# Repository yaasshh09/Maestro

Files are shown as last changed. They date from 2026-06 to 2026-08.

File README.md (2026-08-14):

# Maestro
 
A compact 6-key macropad with a rotary encoder and OLED display, built around the Seeeduino XIAO RP2040 and running QMK firmware. Small footprint, fully custom, and 3D printed.

## Overview
 
This is a 6-key macropad arranged in a 2x3 matrix, with a rotary encoder for analog-style control and a 0.91" OLED for live feedback. It is built on a custom PCB, with the Seeeduino XIAO RP2040 socketed on top. It runs QMK, so every key, layer, and encoder action is fully remappable, and you get access to the entire QMK feature set (layers, tap-dance, macros, combos.
 
The whole thing is housed in a 3D printed case designed to hold the PCB, switches, encoder, OLED, and XIAO board in place.

<p align="center">
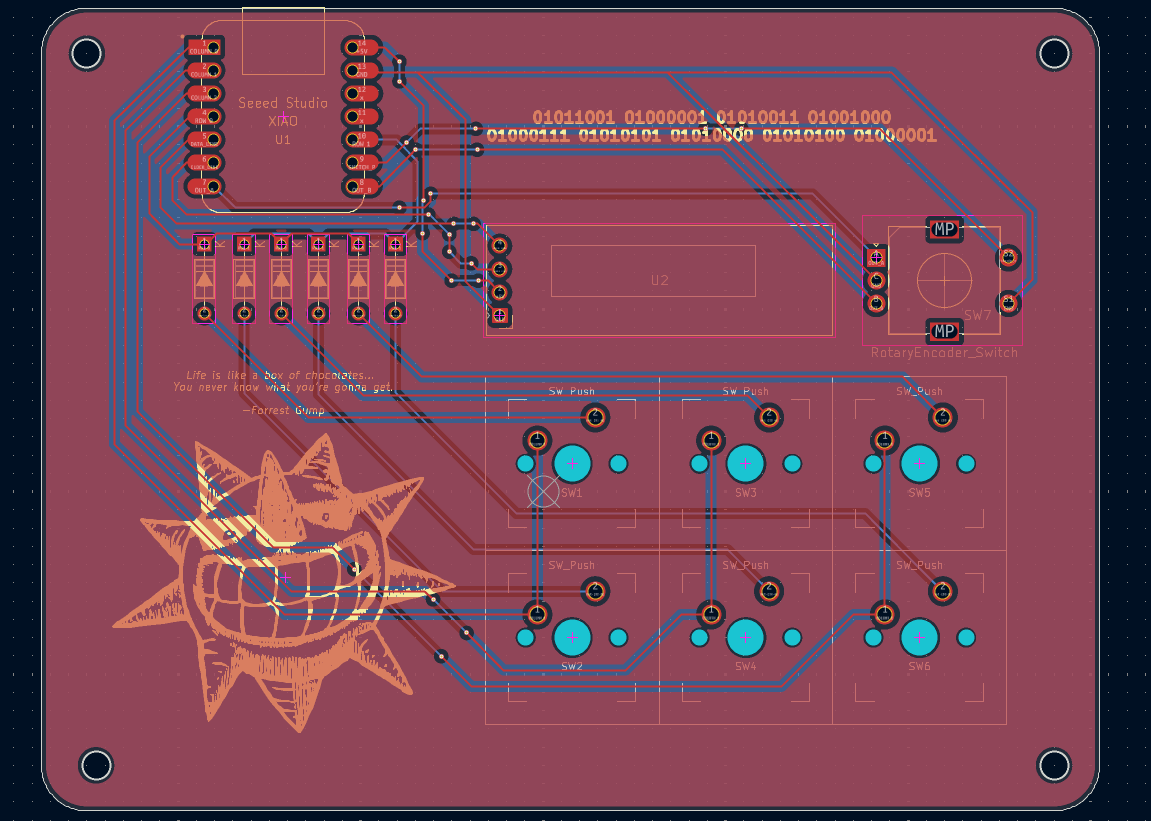
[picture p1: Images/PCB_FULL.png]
PCB_FULL
   
</p>
<p align="center">
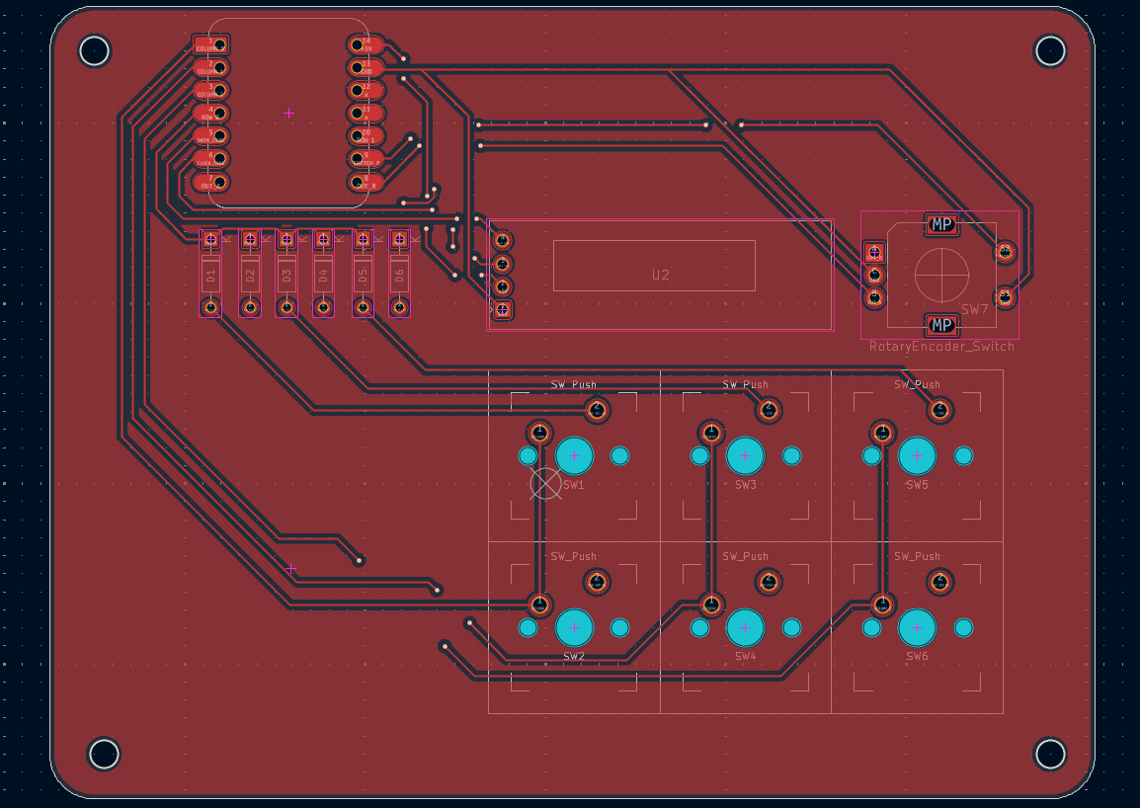
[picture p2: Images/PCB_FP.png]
  
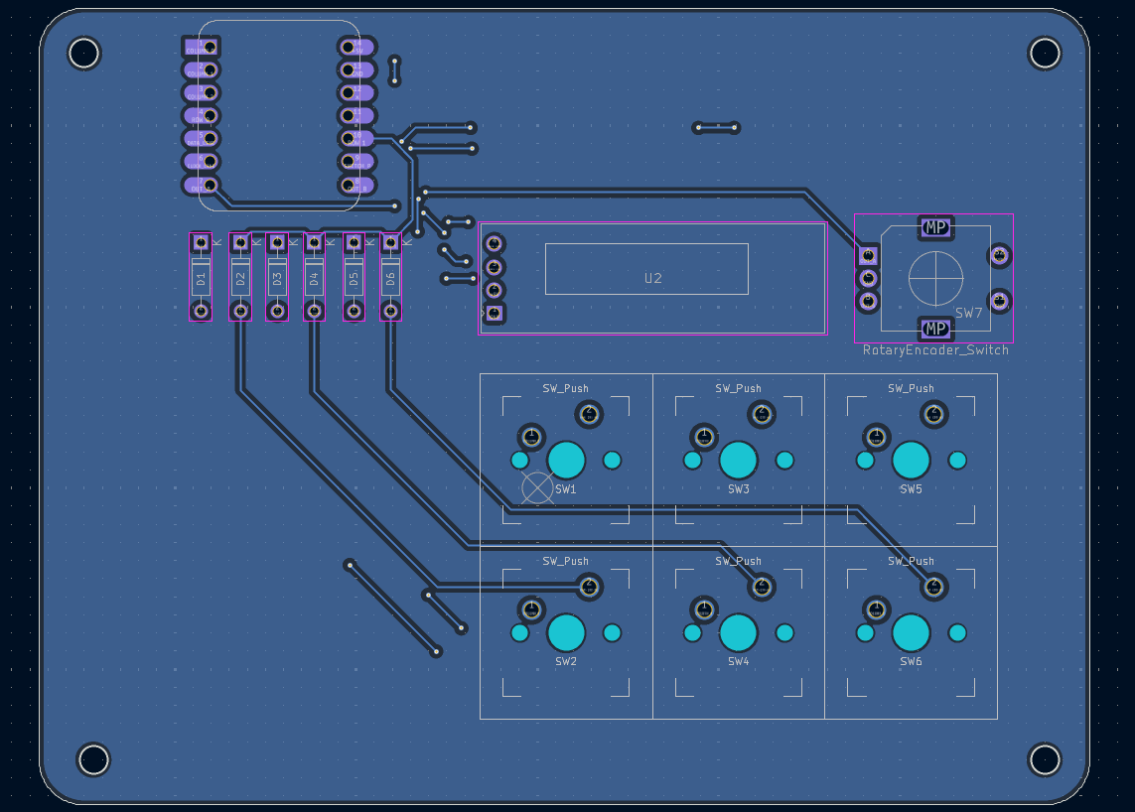
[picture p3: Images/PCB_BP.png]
 
</p>
<p align="center">
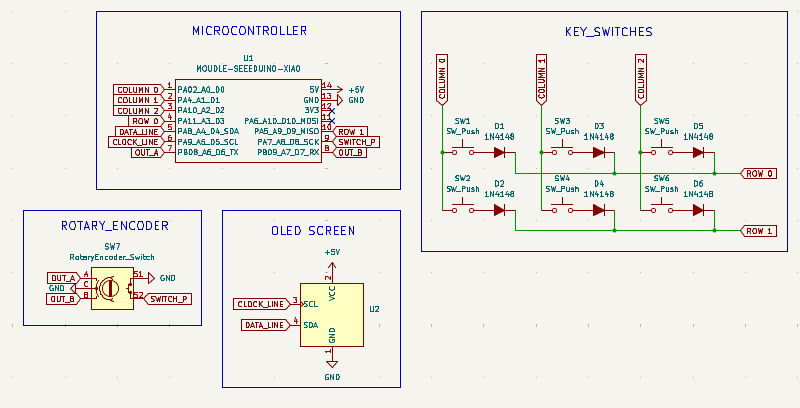
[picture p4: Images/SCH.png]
   
</p>
## Features
 
- 6 mechanical switches wired in a 2x3 matrix
- Rotary encoder with push-button
- 0.91" OLED display for layer and status readout
- Seeeduino XIAO RP2040 microcontroller
- Runs QMK firmware with full layer and macro support
- Custom designed PCB with socketed XIAO RP2040
- 3D printed three-part case

## Bill of Materials
|Amount|Part|
|-|-|
|1x|Seeeduino XIAO RP2040|
|6x|MX-style switches|
|6x|1N4148 diodes|
|1x|EC11 rotary encoder + knob|
|1x|0.91" SSD1306 OLED (I2C, 4-pin)|
|1x|custom PCB|
|1x|3D printed case (top + plate + base)|
|1x|USB-C cable|
 
## FIRMWARE (QMK)
### 1. Set up QMK

If you haven't already, install QMK and its toolchain:

```bash
qmk setup
```

On Windows, run all *qmk* commands inside the *QMK MSYS* terminal that is
installed with QMK.

### 2. Link this keyboard into your QMK tree

Clone this repo, then link `qmk_firmware/keyboards/maestro` to the keyboard
folder here. 

**Useful scripts:**

**Windows**:

```powershell
cd Firmware\Link
.\link-keyboard.ps1                                  
```
*or :*
```powershell
.\link-keyboard.ps1 -QmkHome "D:\path\to\qmk_firmware"
```

### 3. Build
```bash
qmk compile -kb maestro -km default
```

The compiled maestro_default.uf2 is written to the root of your qmk_firmware folder.

### 4. Flash

Put the XIAO RP2040 into bootloader mode. Either drag the `.uf2` onto that drive, or run:

```bash
qmk flash -kb maestro -km default
```

## OLED Display
 
The 0.91" OLED can show whatever you program in `oled_task_user()`. Common uses:
 
- Current active layer
- Caps/lock status
- A logo or small animation
- Encoder mode indicator

*Keep in mind the 128x32 resolution is small, so stick to short text or compact bitmaps.*

## OLED Companion App

OLED Display cant fetch data itself (keyboard has no internet). A Small external companion app runs on the host computer, reads current Spotify track, pushes to pad over raw HID through app.

- Spotify playing: OLED shows song and artist.
- Spotify idle: OLED shows current time and date.

Firmware just displays what the app sends.

**Requires RAW_ENABLE = yes in rules.mk.**
 
---   
 
## CAD

3D printed, three stacked layers:

- Base layer: tray with raised perimeter wall, four corner screw posts, USB-C notch on side. Houses PCB, secured with screws through corner posts.

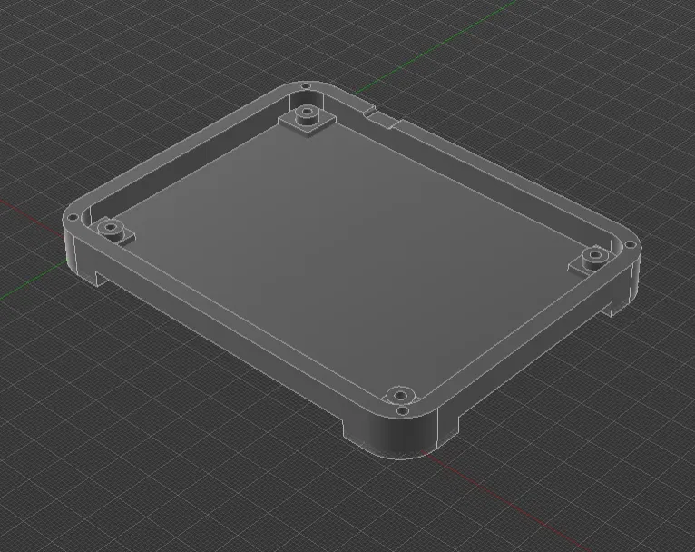
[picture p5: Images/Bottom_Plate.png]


- Plate layer: flat sheet with six square switch cutouts in 2x3 grid and raised border wall. Fixed with single screw at bottom, plus optional superglue for extra hold.

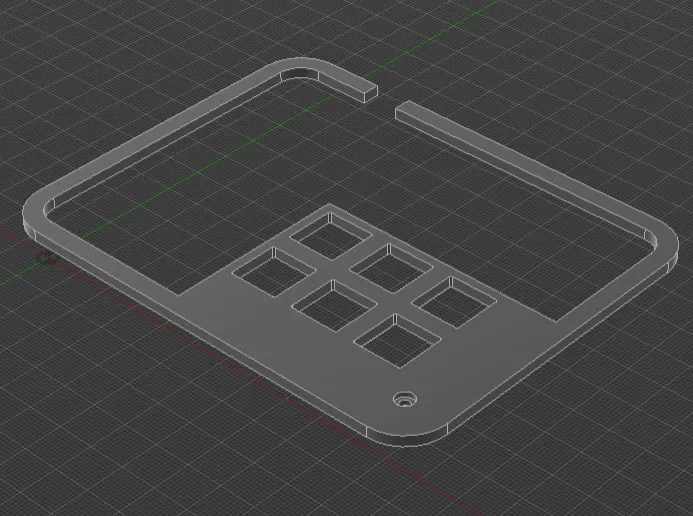
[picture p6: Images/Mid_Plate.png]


- Top layer: frame with large open window to showcase PCB, dedicated cutout slot for OLED and rotary encoder, screw hole, chamfered corners.

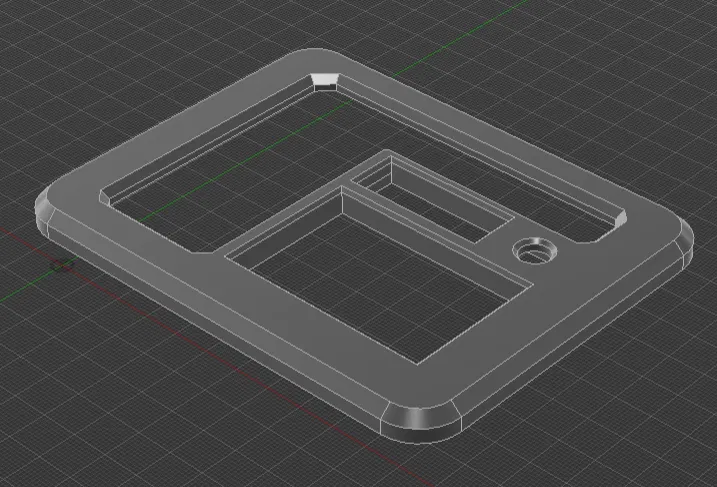
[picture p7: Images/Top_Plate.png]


---

## Notes
 
- Match your matrix and encoder pins in keyboard.json / config.h to the PCB routing before flashing.
- If the OLED does not light up, confirm the I2C address (usually 0x3C) and the header orientation.
- If the keys ghost or repeat, check diode placement and matrix definitions.

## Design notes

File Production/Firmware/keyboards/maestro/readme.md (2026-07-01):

# maestro

A 6-key (2x3) macropad with a rotary encoder and a 0.91" SSD1306 OLED, driven by
a Seeed **XIAO RP2040**.

* Keyboard Maintainer: [Yash](https://github.com/yaasshh09)
* Hardware Supported: Seeed XIAO RP2040 + 6x SW_Push (1N4148 per key), EC11 rotary
  encoder, 0.91" 128x32 SSD1306 OLED (I2C)

> Note: the PCB uses the generic Seeed XIAO footprint and the schematic
> specifies the **XIAO RP2040**, which this firmware targets. If you socket a
> different XIAO variant, update `processor`, `bootloader`, and the pins in
> `keyboard.json` / `config.h`.

## Wiring (schematic net -> XIAO pad -> RP2040 GPIO)

| Net | XIAO pad | GPIO  | Role |
|---|---|---|---|
| COLUMN 0/1/2 | D0/D1/D2 | GP26/GP27/GP28 | Matrix columns |
| ROW 0 | D3 | GP29  | Matrix row 0 |
| ROW 1 | D9 | GP4 | Matrix row 1 |
| DATA_LINE (SDA)| D4 | GP6 | OLED I2C1 SDA |
| CLOCK_LINE(SCL)| D5 | GP7 | OLED I2C1 SCL |
| OUT_A | D6 | GP0 | Encoder A |
| OUT_B | D7 | GP1 | Encoder B |
| SWITCH_P | D8 | GP2 | Encoder push (direct read) |

Diodes are COL2ROW (anode on the column, cathode on the row).

## Default layout

```
┌─────┬─────┬─────┐
│ Undo│ Copy│Paste│
├─────┼─────┼─────┤
│ Cut │ Redo│ Save│
└─────┴─────┴─────┘
  Encoder: turn = volume, press = mute
```

(Ctrl-based shortcuts; remap freely in `keymaps/default/keymap.c`.)

## OLED (now-playing / clock)

The OLED renders 4 rows of text streamed from a PC companion app over Raw HID:
the current Spotify song while playing, otherwise the time & date. Setup lives in
[`Firmware/companion/`](../../companion/README.md). With the app not running, the OLED shows a
static `maestro` fallback. All layout/formatting is in the companion script — no
reflashing needed to change it.

Make example for this keyboard (after setting up your build environment):

    make maestro:default

Flashing example for this keyboard:

    make maestro:default:flash

See the [build environment setup](https://docs.qmk.fm/#/getting_started_build_tools) and the [make instructions](https://docs.qmk.fm/#/getting_started_make_guide) for more information. Brand new to QMK? Start with our [Complete Newbs Guide](https://docs.qmk.fm/#/newbs).

## Bootloader

Enter the bootloader in 2 ways:

* **Double-tap reset**: quickly double-tap the XIAO RP2040 reset button; it mounts
  as a `RPI-RP2` USB drive — drop the `.uf2` on it.
* **Bootmagic reset**: hold the top-left key (matrix `[0,0]`) while plugging in.

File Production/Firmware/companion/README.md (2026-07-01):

# maestro OLED companion

A small background program that streams **now-playing** (Spotify / any Windows
media session) and the **clock** to the maestro macropad's OLED over Raw HID.

The firmware just renders 4 rows of text that this app sends, so you can change
the layout/format by editing `maestro_oled.py` alone — no reflashing.

```
Spotify playing                Nothing playing
┌─────────────────────┐        ┌─────────────────────┐
│ Bohemian Rhapsody    │        │ 14:35:07            │
│ Queen                │        │ Tue 01 Jul 2026     │
│                      │        │                     │
│ Spotify              │        │ maestro             │
└─────────────────────┘        └─────────────────────┘
```
(Long titles/artists scroll automatically.)

See [INSTALL.md](INSTALL.md) for the step-by-step end-user guide.

## Requirements

Use the **python.org** Python (3.9+), *not* the MSYS one bundled with QMK.

```powershell
pip install -r requirements.txt
```

This installs `hidapi` (USB) and `winsdk` (Windows "Now Playing" API).

## Run

```powershell
python maestro_oled.py
```

Leave it running. Plug/unplug is handled — it reconnects automatically. When the
app isn't running, the OLED shows a static `maestro` fallback screen.

## Build a standalone .exe (optional)

If you'd rather have a double-clickable app with no Python install, build one
yourself from the source (nothing prebuilt ships in this repo, so you run only
code you can inspect):

```powershell
pip install pyinstaller
pyinstaller --onefile --name maestro-oled --collect-all winsdk maestro_oled.py
# result: dist\maestro-oled.exe
```

## Start automatically at login

Easiest: drop a shortcut in the Startup folder.

1. Press `Win+R`, type `shell:startup`, Enter.
2. Create a shortcut in that folder pointing to:
   ```
   pythonw.exe "C:\Users\yashg\qmk_firmware\keyboards\maestro\companion\maestro_oled.py"
   ```
   (`pythonw.exe` runs it with no console window.)

Or use Task Scheduler with "At log on" if you prefer.

## Customizing the display

Everything is in `maestro_oled.py`:

- `clock_screen()` — what shows when nothing is playing (time/date format).
- `now_playing_screen()` — the song layout (title/artist/labels).
- `POLL_SECONDS` — refresh + scroll speed.
- The OLED is **4 rows × 21 chars**; anything longer scrolls via `marquee()`.

## Notes / limits

- "Now Playing" reads **local** playback on this PC (Spotify desktop, browsers).
  Playback on your phone won't show unless this PC is the active device.
- The constants `VID/PID/USAGE_PAGE/USAGE` must match the firmware. If you change
  the keyboard's USB IDs in `keyboard.json`, update them here too.

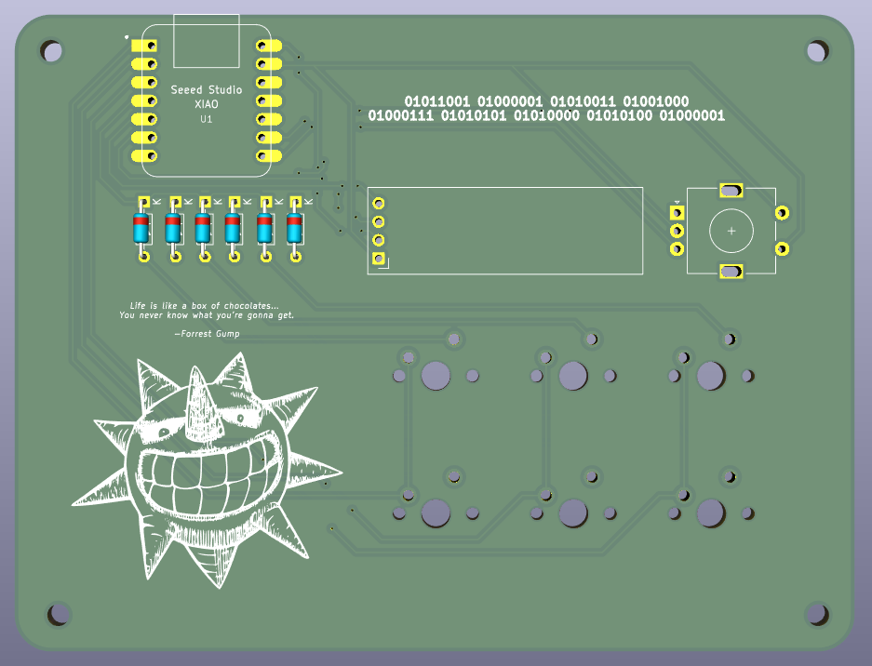
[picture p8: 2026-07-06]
Images/PCB_3DF.png

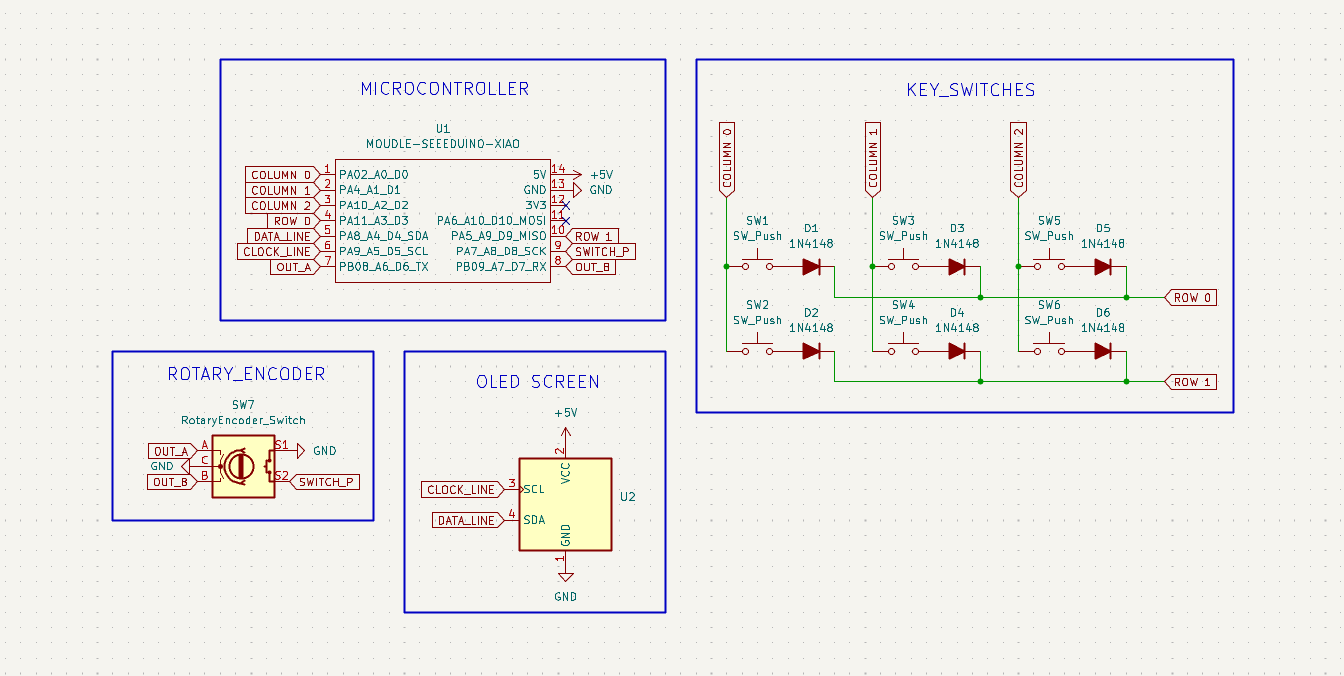
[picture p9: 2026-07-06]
Images/Sch_Full.png

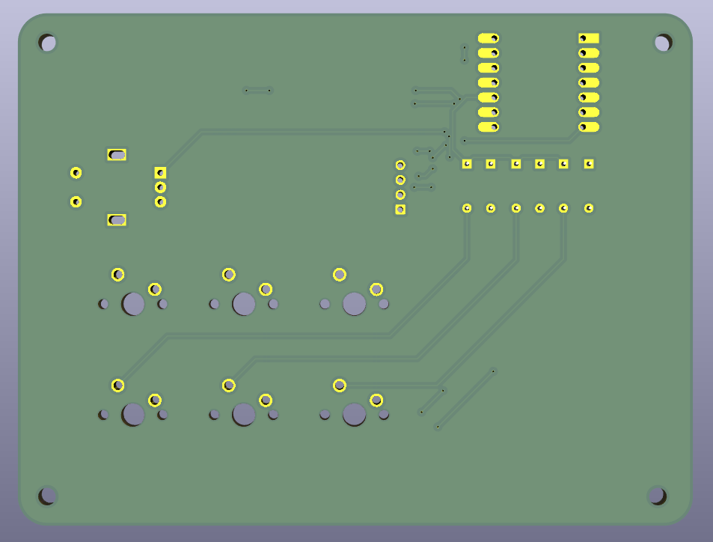
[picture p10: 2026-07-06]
Images/PCB_3DB.png

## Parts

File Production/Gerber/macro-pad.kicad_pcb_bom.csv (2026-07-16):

Designator | Quantity | Value | Footprint | Package | MPN | DNP | Mount_Type | Description
D1, D2, D3, D4, D5, D6 | 6 | 1N4148 | D_DO-35_SOD27_P7.62mm_Horizontal |  |  |  | tht | DO-35 Diode, Small Signal, Fast Switching, 75V, 150mA, 4ns, Alternate KiCad Library
SW1, SW2, SW3, SW4, SW5, SW6 | 6 | SW_Push | MX-Solderable-1U |  |  |  | tht | Push button switch, generic, two pins
SW7 | 1 | RotaryEncoder_Switch | RotaryEncoder_Alps_EC11E-Switch_Vertical_H20mm |  |  |  | tht | Rotary encoder, dual channel, incremental quadrate outputs, with switch
U1 | 1 | MOUDLE-SEEEDUINO-XIAO | XIAO-Generic-Hybrid-14P-2.54-21X17.8MM |  |  |  | smt
U2 | 1 | ER_OLEDM0.91_1x-I2C | ER_OLEDM0.91_1x-I2C |  |  |  | tht | SSD1306 OLED module, 0.91 inch, 128x32, I2C

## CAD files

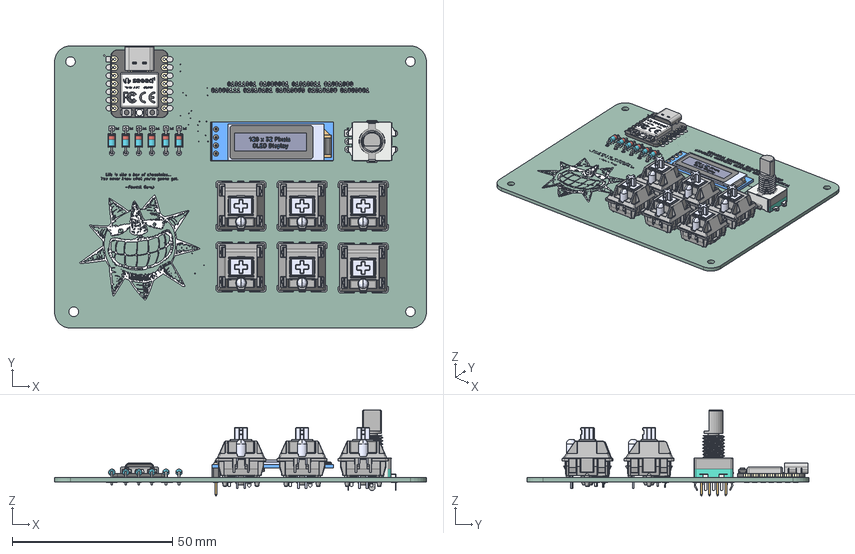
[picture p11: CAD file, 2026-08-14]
CAD/STEP/PCB_Main_Detailed.step
116.0 x 88.0 x 26.8 mm

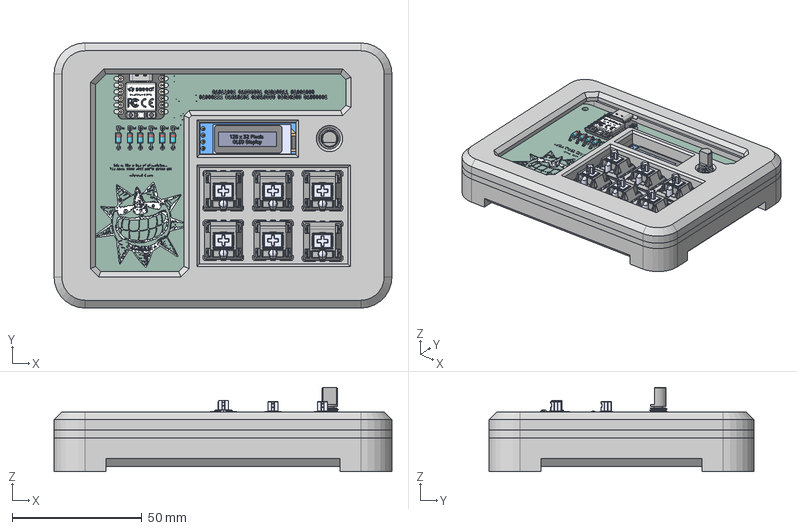
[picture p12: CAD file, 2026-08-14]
CAD/STEP/Maestro_Assembly.step
130.0 x 102.0 x 32.4 mm

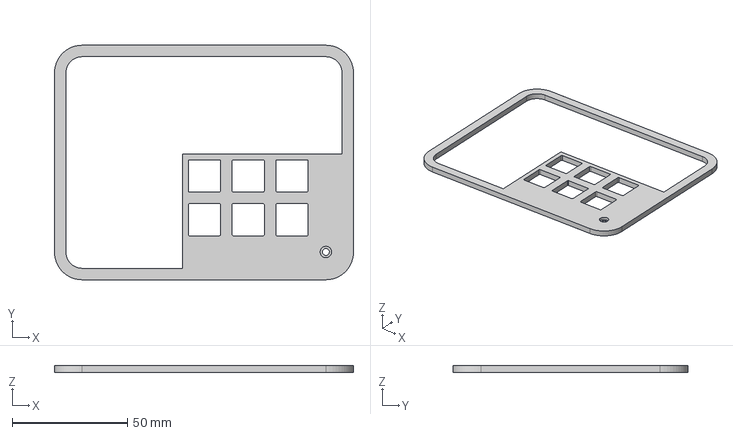
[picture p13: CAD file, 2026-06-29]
CAD/STEP/Plate_Main.step
130.0 x 102.0 x 3.00 mm

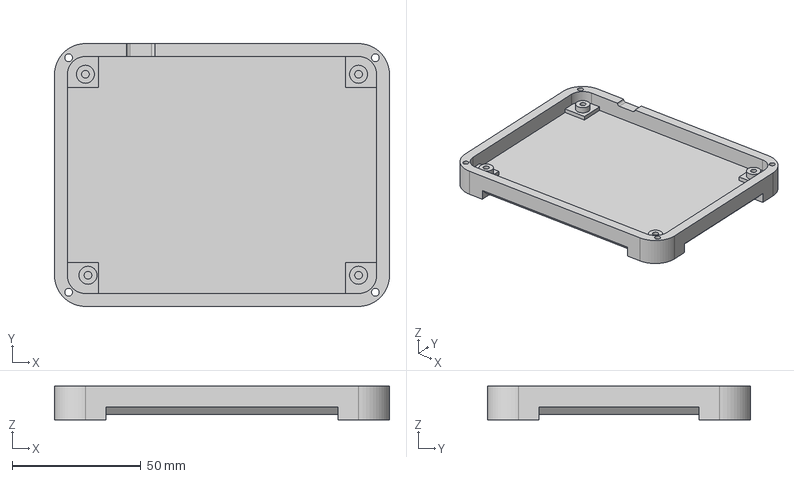
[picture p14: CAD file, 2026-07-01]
CAD/STEP/Base_Layer.step
130.0 x 102.0 x 13.0 mm

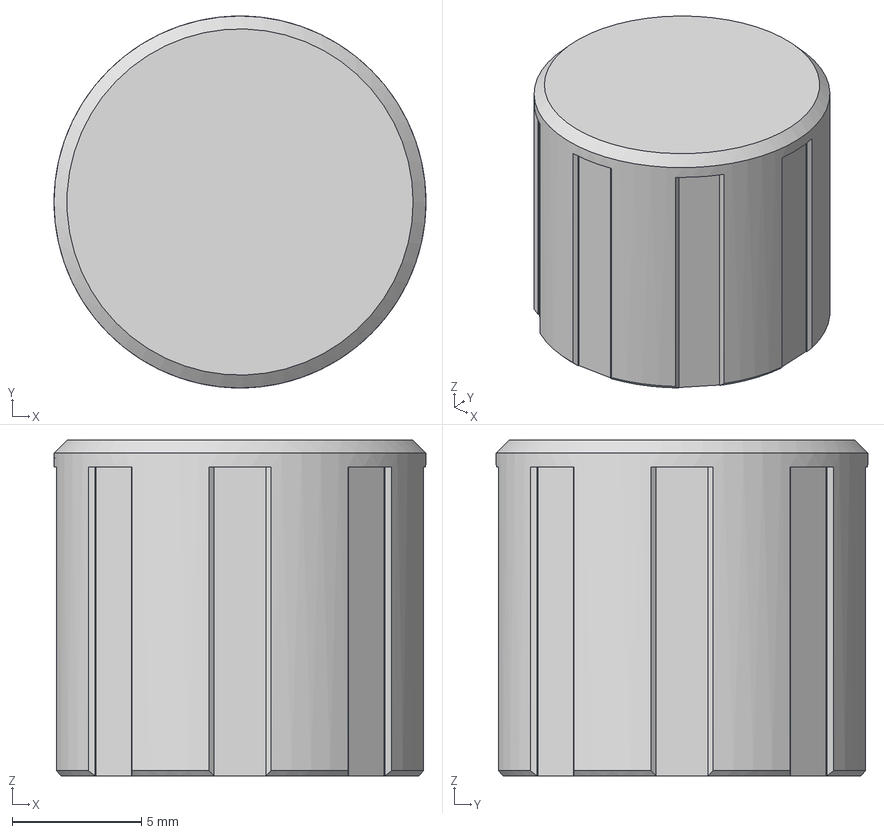
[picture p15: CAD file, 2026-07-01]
Production/CAD/STEP/Rotary_Encoder_Knob.step
14.4 x 14.4 x 13.0 mm

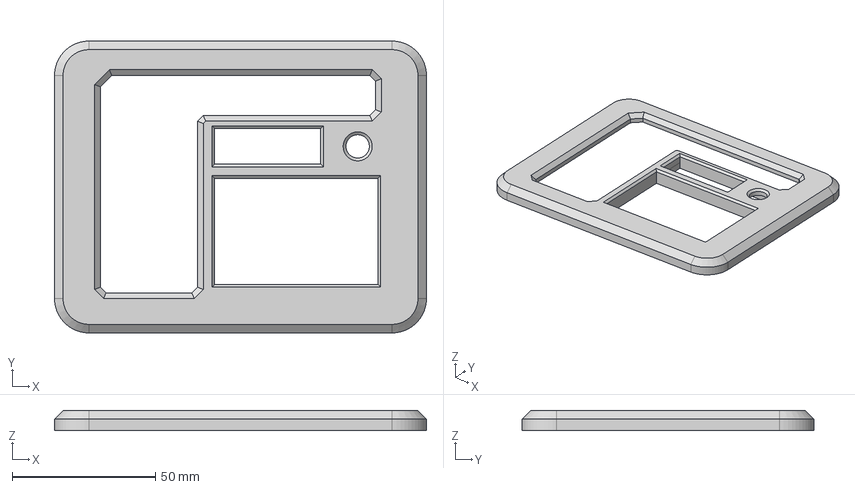
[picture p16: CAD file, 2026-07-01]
Production/CAD/STEP/Top_Layer.step
130.0 x 102.0 x 7.00 mm

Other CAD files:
CAD/STEP/PCB_Main.step
Production/CAD/STEP/PCB_Main.step
CAD/STEP/Plate_Layer.step
Production/CAD/STEP/Plate_Layer.step
CAD/SOURCE/Base_Layer.f3d
CAD/SOURCE/Maestro_Assembly.f3z
CAD/SOURCE/Plate_Layer.f3d
CAD/SOURCE/Top_Layer.f3d
CAD/STL/Base_Layer.stl
CAD/STL/Plate_Layer.stl
CAD/STL/Top_Layer.stl
Production/CAD/SOURCE/Base_Layer.f3d
Production/CAD/SOURCE/Maestro_Assembly.f3z
Production/CAD/SOURCE/Plate_Layer.f3d
Production/CAD/SOURCE/Top_Layer.f3d
Production/CAD/STL/Base_Layer.stl
Production/CAD/STL/Plate_Layer.stl
Production/CAD/STL/Top_Layer.stl

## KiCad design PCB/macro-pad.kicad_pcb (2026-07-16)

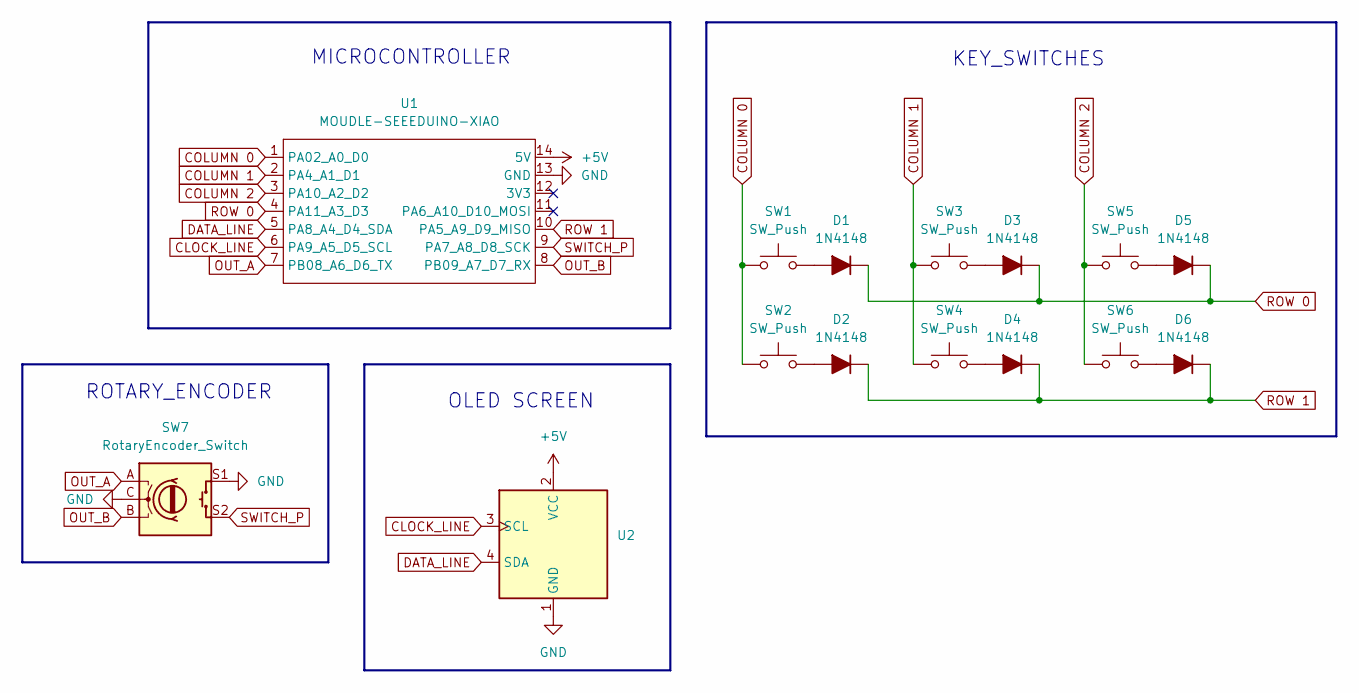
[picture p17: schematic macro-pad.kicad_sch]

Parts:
D1, D2, D3, D4, D5, D6: 1N4148; D_DO-35_SOD27_P7.62mm_Horizontal
SW1, SW2, SW3, SW4, SW5, SW6: SW_Push; MX-Solderable-1U
SW7: RotaryEncoder_Switch; RotaryEncoder_Alps_EC11E-Switch_Vertical_H20mm
U1: MOUDLE-SEEEDUINO-XIAO; XIAO-Generic-Hybrid-14P-2.54-21X17.8MM
U2: ER_OLEDM0.91_1x-I2C

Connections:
+5V: U1.14 (5V), U2.2 (VCC)
CLOCK_LINE: U1.6 (PA9_A5_D5_SCL), U2.3 (SCL)
COLUMN 0: SW1.1, SW2.1, U1.1 (PA02_A0_D0)
COLUMN 1: SW3.1, SW4.1, U1.2 (PA4_A1_D1)
COLUMN 2: SW5.1, SW6.1, U1.3 (PA10_A2_D2)
DATA_LINE: U1.5 (PA8_A4_D4_SDA), U2.4 (SDA)
GND: SW7.C, SW7.S1, U1.13 (GND), U2.1 (GND)
unnamed: D1.2 (A), SW1.2
unnamed: D2.2 (A), SW2.2
unnamed: D3.2 (A), SW3.2
unnamed: D4.2 (A), SW4.2
unnamed: D5.2 (A), SW5.2
unnamed: D6.2 (A), SW6.2
OUT_A: SW7.A, U1.7 (PB08_A6_D6_TX)
OUT_B: SW7.B, U1.8 (PB09_A7_D7_RX)
ROW 0: D1.1 (K), D3.1 (K), D5.1 (K), U1.4 (PA11_A3_D3)
ROW 1: D2.1 (K), D4.1 (K), D6.1 (K), U1.10 (PA5_A9_D9_MISO)
SWITCH_P: SW7.S2, U1.9 (PA7_A8_D8_SCK)

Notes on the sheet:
MICROCONTROLLER
OLED SCREEN
KEY_SWITCHES
ROTARY_ENCODER

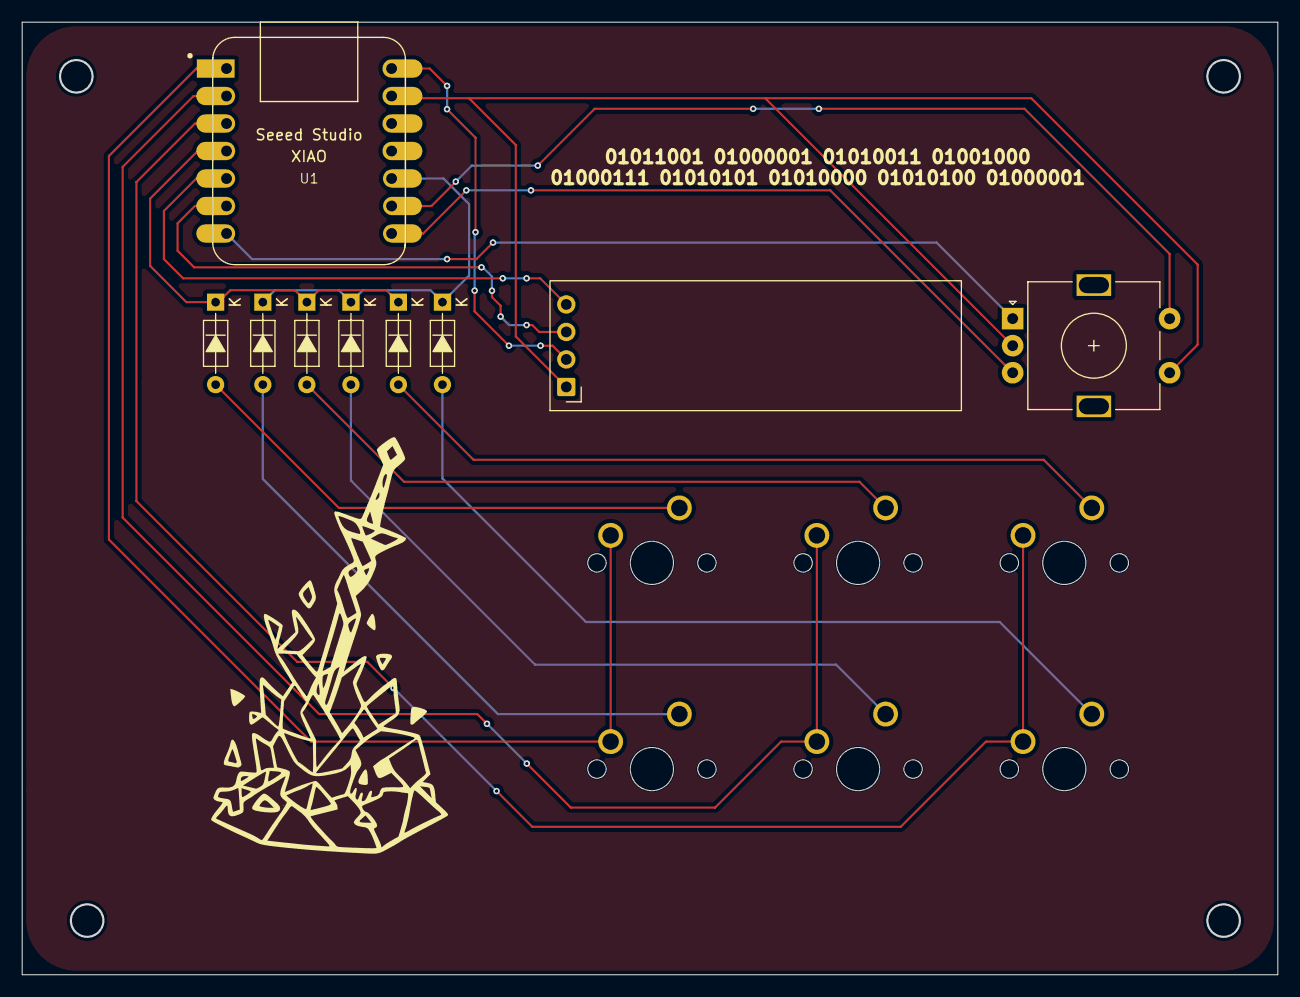
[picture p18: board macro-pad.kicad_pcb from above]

Board: 2 copper layers, 116.0 x 88.0 mm, 15 parts (0 on the bottom side), 18 nets.

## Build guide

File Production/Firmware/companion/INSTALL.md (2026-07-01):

# maestro OLED app — install guide

This little app makes your **maestro macropad's screen** show the song you're
playing (Spotify or any media), and the time & date when nothing is playing.

It's a small Python script — you run it from source, so you can see exactly what
it does.

## Install (Windows)

1. Install **Python 3.9+** from [python.org](https://www.python.org/downloads/)
   (tick *"Add Python to PATH"* during setup). Use this Python, **not** the one
   bundled with QMK MSYS.
2. Open PowerShell in this `companion` folder and install the dependencies:
   ```powershell
   pip install -r requirements.txt
   ```
3. Run it:
   ```powershell
   python maestro_oled.py
   ```
   A small window shows the status ("Connected to maestro" once your macropad is
   plugged in).
4. Play something on Spotify — it appears on the macropad's screen.

> Prefer a double-clickable app with no console window? You can build your own
> `.exe` from this source — see **Build a standalone .exe** in
> [README.md](README.md).

## Start it automatically at login

So the screen "just works" every time you turn on your PC:

1. Press `Win + R`, type `shell:startup`, press Enter.
2. Create a shortcut in that folder pointing to:
   ```
   pythonw.exe "<path-to-this-folder>\maestro_oled.py"
   ```
   (`pythonw.exe` runs it quietly with no console window.)

Now it launches quietly whenever you log in.

## What it shows

```
While playing                  When idle
┌─────────────────────┐        ┌─────────────────────┐
│ Song title           │        │ 14:35:07            │
│ Artist               │        │ Tue 01 Jul 2026     │
│                      │        │                     │
│ Spotify              │        │ maestro             │
└─────────────────────┘        └─────────────────────┘
```

## Notes

- It reads media playing **on this PC** (Spotify desktop app, browsers, etc.).
- If the macropad isn't plugged in, the app just waits for it — no harm done.
- To stop it, close the window (or end the `python` process in Task Manager).

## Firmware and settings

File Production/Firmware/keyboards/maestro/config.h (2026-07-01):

// Copyright 2026 Yash (@yaasshh09)
// SPDX-License-Identifier: GPL-2.0-or-later

#pragma once

/* Enter the RP2040 UF2 bootloader by double-tapping the reset/BOOT button. */
#define RP2040_BOOTLOADER_DOUBLE_TAP_RESET
#define RP2040_BOOTLOADER_DOUBLE_TAP_RESET_TIMEOUT 500U

/* 0.91" SSD1306 OLED is wired to D4 (SDA) / D5 (SCL) = GP6 / GP7 = I2C1. */
#define I2C_DRIVER I2CD1
#define I2C1_SDA_PIN GP6
#define I2C1_SCL_PIN GP7

#ifdef OLED_ENABLE
#    define OLED_DISPLAY_128X32
#    define OLED_TIMEOUT 60000
#    define OLED_BRIGHTNESS 128
#endif

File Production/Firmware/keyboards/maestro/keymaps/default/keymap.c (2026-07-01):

// Copyright 2026 Yash (@yaasshh09)
// SPDX-License-Identifier: GPL-2.0-or-later

#include QMK_KEYBOARD_H
#include <string.h>

#ifdef RAW_ENABLE
#    include "raw_hid.h"
#endif


#define ENCODER_SW_PIN     GP2
#define ENCODER_SW_KEYCODE KC_MUTE

const uint16_t PROGMEM keymaps[][MATRIX_ROWS][MATRIX_COLS] = {
    [0] = LAYOUT_ortho_2x3(
        C(KC_Z),  C(KC_C),  C(KC_V),
        C(KC_X),  C(KC_Y),  C(KC_S)
    )
};

#ifdef ENCODER_ENABLE
bool encoder_update_user(uint8_t index, bool clockwise) {
    tap_code(clockwise ? KC_VOLU : KC_VOLD);
    return false;
}
#endif

void keyboard_post_init_user(void) {
    // Encoder switch: input with internal pull-up, switch shorts to GND (active-low).
    gpio_set_pin_input_high(ENCODER_SW_PIN);
}

void housekeeping_task_user(void) {
    static bool     pressed  = false;
    static uint16_t debounce = 0;

    bool reading = !gpio_read_pin(ENCODER_SW_PIN); // active-low
    if (reading != pressed && timer_elapsed(debounce) > 5) {
        pressed  = reading;
        debounce = timer_read();
        if (pressed) {
            register_code(ENCODER_SW_KEYCODE);
        } else {
            unregister_code(ENCODER_SW_KEYCODE);
        }
    }
}

#define OLED_TEXT_COLS 21
#define OLED_TEXT_ROWS 4
#define HOST_TIMEOUT_MS 5000

#ifdef RAW_ENABLE
static char     host_screen[OLED_TEXT_ROWS][OLED_TEXT_COLS + 1] = {0};
static uint32_t host_last_update                                 = 0;

// Each report: data[0] = row index (0-3), data[1..] = ASCII text for that row.
void raw_hid_receive(uint8_t *data, uint8_t length) {
    uint8_t row = data[0];
    if (row < OLED_TEXT_ROWS) {
        memset(host_screen[row], 0, sizeof(host_screen[row]));
        for (uint8_t i = 0; i < OLED_TEXT_COLS && (i + 1) < length; i++) {
            char c = (char)data[i + 1];
            if (c == 0) {
                break;
            }
            host_screen[row][i] = c;
        }
    }
    host_last_update = timer_read32();
#    ifdef OLED_ENABLE
    oled_on(); // keep the screen awake while the app is feeding it
#    endif
}
#endif

#ifdef OLED_ENABLE
oled_rotation_t oled_init_user(oled_rotation_t rotation) {
    return OLED_ROTATION_0;
}

static void oled_write_padded(const char *text) {
    uint8_t len = (uint8_t)strlen(text);
    oled_write(text, false);
    for (uint8_t c = len; c < OLED_TEXT_COLS; c++) {
        oled_write_char(' ', false); // clear any stale characters on the line
    }
}

bool oled_task_user(void) {
#    ifdef RAW_ENABLE
    if (timer_elapsed32(host_last_update) < HOST_TIMEOUT_MS) {
        for (uint8_t r = 0; r < OLED_TEXT_ROWS; r++) {
            oled_set_cursor(0, r);
            oled_write_padded(host_screen[r]);
        }
        return false;
    }
#    endif
    // Companion app not running -> static fallback.
    oled_write_P(PSTR("maestro\n"), false);
    oled_write_P(PSTR("\n"), false);
    oled_write_P(PSTR("turn: vol\n"), false);
    oled_write_P(PSTR("press: mute"), false);
    return false;
}
#endif

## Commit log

2026-06-29 Initial commit of my folder
    [Plate_Main.step]
2026-06-30 Added KiCad Files
    [macro-pad.kicad_pcb, macro-pad.kicad_sch]
2026-07-01 Enhance README with project details and instructions
    Added detailed project description, features, hardware specifications, assembly instructions, firmware setup, and CAD information for the Maestro macropad.
2026-07-01 CAD files added
    [Base_Layer.step, Plate_Layer.step, Plate_Main.step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]
2026-07-16 Updated the .kicad_pcb
    [macro-pad.kicad_pcb, macro-pad.kicad_pcb_bom.csv, macro-pad.kicad_pcb_positions.csv]
2026-08-14 Prod Folder
    [Base_Layer.f3d, Base_Layer.step, Base_Layer.stl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]
